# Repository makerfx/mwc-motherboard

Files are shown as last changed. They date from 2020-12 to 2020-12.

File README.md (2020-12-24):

# Magic Wheelchair Motherboard

The Magic Wheelchair Motherboard is a printed circuit board that makes it much easier to add interactivity to Magic Wheelchair builds (or other interactive projects).

Features include:
* Plug-in support for Teensy 4.1 and the Teensy 4 audio audio adaptor
* 4 channels of non-blocking addressable LEDs (ws2812, neopixel, etc.) full compatible with FastLED
* Stereo sound input, processing and output including volume control, filters, polyphonic sound output, multiple channels of simultaneous sd-card playback, FFT and peak level analysis and much more.
* Level-shifted GPIO
* Full breakout of all Teensy pins
* .91" OLED Screen for debugging or status
* Multiple channels of high-current transistor driven output
* Selectable voltage (5v or 12v) for addressable LED outputs
* Pluggable connectors for VIN, LED outputs and high-current outputs
* Small prototyping area for adding additional components
* Expansion header for connecting to a daughterboard
* Support for USB host mode through the Teensy 4.1 USB header

Note that this board is still in the development and testing phase. If you are interested in obtaining a board for a Magic Wheelchair project, or for another interactive project, [email us](mailto:info@makerfx.org) to learn the current status and availability of boards.
___
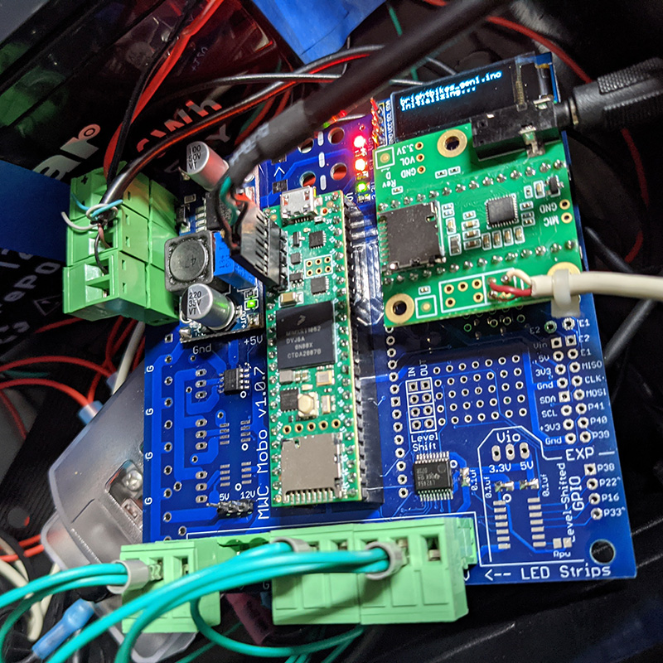
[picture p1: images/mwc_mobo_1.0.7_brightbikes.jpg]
MWC Motherboard prototype

MWC Motherboard prototype v1.0.7 being tested in a [BrightBikes](https://github.com/makerfx/brightbikes) LED art bike with more than 1600 audio-interactive addressable LEDs

BrightBikes holiday ride

BrightBikes fire demo

___
## History
In 2019, [we built the Bumblebee Transformer Magic Wheelchair for Alex](https://makezine.com/2019/02/08/watch-these-makers-transform-a-wheelchair-into-an-interactive-bumblebee-costume/) - that project was completed in just a few weeks, and we used the Teensy 3.6 with the Teensy 3 Audio Shield. We hand soldered protoboards for the circuits including the Teensy components, level shifters and high-current transistor outputs. Alex loved Bumblebee and Magic Wheelchair builders provided very positive feedback on the interactivity of the build. Just two weeks later, we were asked to help provide the electronics for another MWC build in Portland. Again, we created a hand-soldered protoboard. We realized that if we could make this part easier with a plug & play board for interactive MWC builds, we could help the build community significantly.

We've now worked through 7 revisions of the board, including upgrading to the Teensy 4.1 and the Teensy 4 Audio shield. We've added more functionality, and made it easier than every to get started. All our MWC build code is Open Source and available here to get builders up-to-speed quickly.

## Example Uses
* [Magic Wheelchair builds using this design]((http://www.makerfx.org/magic-wheelchair])) (includes prior generations of this circuit before the motherboard was created)
  * [Bumblebee Transformer code on GitHub](https://github.com/makerfx/mwc-bumblebee)
  * [Star Wars Tie Silencer code on GitHub](https://github.com/makerfx/mwc-tie-silencer)
  * [Guarians of the Galaxy Milano code on GitHub](https://github.com/makerfx/mwc-guardians-milano)
* BrightBikes - [Facebook](www.facebook.com/brightbikesorl) and [GitHub](https://github.com/makerfx/brightbikes)

## Bill of Materials
Note, not all parts are required. For example, if your build does not use high-current outputs, you don't need to populate those parts.

* PCB
  * If you want to purchase bare or populated boards, we are planning to make them available at some point in the future. Note that this board is still in the development and testing phase. If you are interested in obtaining a board for a Magic Wheelchair project, or for another interactive project, [email us](mailto:info@makerfx.org) to learn the current status and availability of boards.

* Teensy 4.1
  * QTY 1
  * Order from [PJRC](https://www.pjrc.com/store/teensy41.html) to support the creator.
  * We install header pins, so you can order with or without pins.

* Teensy Audio Adaptor Rev D
  * QTY 1
  * Order from [PJRC](https://www.pjrc.com/store/teensy3_audio.html) to support the creator.
  * REV D is for the Teensy 4 series, make sure you get the correct revision!
  * We install header pins, so you can order with or without pins.
  * This part is not required if the project does not have audio (but why not?!)

* LM2596 DC-DC Power Supply
  * QTY 1
  * [Amazon example](https://www.amazon.com/gp/product/B07VVXF7YX/)
  * Note that footprint is very important, there are several versions of similar boards
  * We typically run these systems off 12v batteries, this part does the regulation down to 5v, then the Teensy regulator provides 3.3v
  * SET THIS PART TO 5V BEFORE TYING ITS OUTPUTS TO THE PCB!

* .91" OLED Display (i2c)
  * QTY 1
  * [Amazon example](https://www.amazon.com/MELIFE-Display-SSD1306-3-3V-5V-Arduino/dp/B08F1ZBGLN/)
  * This part is optional and can be used for debugging or status displays. They are inexpensive and very helpful

* 2 pin Plug-in Screw terminal block 5.08mm pitch
  * QTY 8 (QTY 1 for VIN, QTY 5 for optional high-current out, QTY 2 for optional addl 5v and GND out)
  * [Amazon right angle example](https://www.amazon.com/gp/product/B07317PFSH/)
  * You can use straight or right angle as your packaging dictates

* 3 pin Plug-in Screw Terminal Block 5.08mm pitch
  * QTY 4 for LED outputs
  * [Amazon right angle example](https://www.amazon.com/gp/product/B07TC4WHZJ/)
  * You can use straight or right angle as your packaging dictates

* Male & Female header for mounting Teensy and Audio Adaptor and other items
  * QTY (Approx 80 pins female and 90 pins male for base use)
  * [Amazon set example](https://www.amazon.com/gp/product/B06Y4S6G29/)

* Settings jumpers [Amazon example](https://www.amazon.com/gp/product/B07Q3CDPXF)
  * QTY 2 (QTY 1 for LED voltage output, QTY 1 for level-shifted GPIO voltage)
  * We like red as a visual reminder to manage settings!

* LEDs
  * RED VIN LED SMD 0805
    * QTY 1
    * [Mouser example](https://www.mouser.com/ProductDetail/645-599-0110-007F/)
  * Orange 5V LED SMD 0805
    * QTY 1
    * [Mouser example](https://www.mouser.com/ProductDetail/645-599-0130-007F/)
  * Green 3.3V LED SMD 0805
    * QTY 1
    * [Mouser example](https://www.mouser.com/ProductDetail/645-599-0181-007F/)
  * LED Resistors
    * ADD PART HERE
    * QTY 3

* Addressable LED Output Buffer
  * SN74LV245ADBR Bus Transceiver [Datasheet](http://www.ti.com/general/docs/suppproductinfo.tsp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)
  * QTY 1
  * [Mouser](https://www.mouser.com/ProductDetail/595-SN74LV245ADBR/)
  * Technically this is optional, but if you aren't using the LEDs, this is likely not the right board for you!

* High-Current Output Drivers
  * TC4427ACOA713 Gate Driver 1.5A Dual [Datasheet](https://www.mouser.com/datasheet/2/268/21423F-63366.pdf)
  * QTY 3 (can be optionally populated based on number of high current outputs needed)
  * [Mouser](https://www.mouser.com/ProductDetail/579-TC4427ACOA713/)

* GPIO Level Shifter
  * TXS0104EDR BiDirectional Voltage Level Translator [datasheet](http://www.ti.com/general/docs/suppproductinfo.tsp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)
  * QTY 1 (optional)
  * [Mouser](https://www.mouser.com/ProductDetail/595-TXS0104EDR/)

* Misc Capacitors
  * .1uF SMD 0805
  * QTY 4? (Need to verify)
  * [Mouser Example](https://www.mouser.com/ProductDetail/581-08055C104K/)

* Battery Monitoring circuit (optional)
  * RvH
    * 4.7k SMD 0805 resistor
  * RvL
    * 1k SMD 0805 resistor
  * VRH
    * 1k SMD 0805 resistor
  * VCL
    * .1uF SMD 0805 capacitor
    * same as above in "Misc Capacitors
  * Vref
    * ZTL431BFFTA 2.5V reference - [Datasheet](https://www.mouser.com/datasheet/2/115/ZTL431-432-1499165.pdf)
    * QTY 1
    * [Mouser](https://www.mouser.com/ProductDetail/621-ZTL431BFFTA/)

* Other Handy Items
  * USB 5-pin header cable for Teensy 4.1 host mode
    * QTY 1
    * This is SUPER handy for adding a remote or other USB accessory
    * [Amazon example](https://www.amazon.com/Duttek-2-Pack-Motherboard-Adapter-Extender/dp/B06Y5RKMT8)
  * USB Remote
    * You can read all the buttons on this remote with the Teensy
    * It also supports a mouse mode
    * [Amazon](https://www.amazon.com/gp/product/B01FVUGPE8/)
  * 1/8" Headphone cable for audio input
    * I typically find a recycled cable, cut the end off and solder to the Teensy audio adapter input pads
  * 1/8" Headphone cable for audio output
    * I typically use a recycled headphone cable
  * Audio noise filter
    * Can be very helpful to reduce noise from LEDs in the circuit
    * (Amazon example)[https://www.amazon.com/dp/B0171PQLB8/]
  * Fuse block
    * If you have a LOT of LEDs, you may want to fuse the power circuits
    * We like the models that have bus terminals for both power AND ground
    * [Amazon example](https://www.amazon.com/gp/product/B08928WKGR)
  * 12v battery
    * We like this 12v LiFePo battery - we get about 2 hours of runtime from the 1600 LED art bikes, but these weigh 1/3 of the SLA equivalent!
    * Kaster 12.8V 12Ah LiFePO4 battery [eBay](https://www.ebay.com/itm/Kastar-12V-12AH-LifePO4-Battery-for-CATV-System-Robotics-E-Bike-Motorbike/254618882962)

## Disclaimer
This is a community-driven project and only affiliated with Magic Wheelchair as we are part of the builder community. The Magic Wheelchair organization is not responsible for any of this content, the design of the board, or any software.

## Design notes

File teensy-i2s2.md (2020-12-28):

# Teensy I2S Audio Input

For interactive audio projects, we've been using an external bluetooth receiver with an analog output to run into the Teensy Audio Adaptor analog input. While this works, the path is susceptible to noise, and it adds an extra module / cables.

Ideally, we'd like to take a Bluetooth audio module such as the CSR A64215 [Datasheet](https://www.tinyosshop.com/datasheet/CSRA64215%20QFN%20Data%20Sheet.pdf) and connect it directly to the Teensy via the second I2S input which uses the [i2s2 object in the Teensy Audio System Design Tool](https://www.pjrc.com/teensy/gui/?info=AudioInputI2S2).

## Teensy I2S Input Documentation

* Pins
  * Pin 3: LRCLK Output
    * This outputs the audio system frequency, typically 44.1kHz
  * Pin 4: BCLK Output
    * (This isnt working for me currently, so I don't have confirmed output)
  * Pin 5: RX Input
  * Pin 33: MCLK Output
    * This outputs 11.2 mHz
    * Not all devices need MCLK, the CSRA64215 does not appear to need MCLK

* Audio System Design Tool Object
  * There is an [i2s2 object in the Teensy Audio System Design Tool](https://www.pjrc.com/teensy/gui/?info=AudioInputI2S2) It has no configuration. Simply declaring it enables the output clocks.

* Master / Slave
  * The Teensy is best equipped to run as the master, and you send the clocks to the slave device, and then send the resulting audio data back to the Teensy.
  * The Teensy CAN run as a slave but then the [other audio in the system will not be clocked properly and *bad things happen*](https://forum.pjrc.com/threads/53824-Teensy-3-6-I2S-Slave-Mode-Question?p=188318&viewfull=1#post188318).

* Sample Rate
  * The Teensy operates at 44.1kHz by default. [It is possible to change this, and an easy change - however it can break a number of audio system functions](https://forum.pjrc.com/threads/60272-Time-for-a-new-Audiolibrary?p=236411&viewfull=1#post236411)
  * The CSRA64215 module runs at 48kHz by default, but has a configuration to change to other frequencies.

## CSRA64215 Documentation

* [CSRA64215 Datasheet](https://www.tinyosshop.com/datasheet)
* I purchased a common breakout on eBay
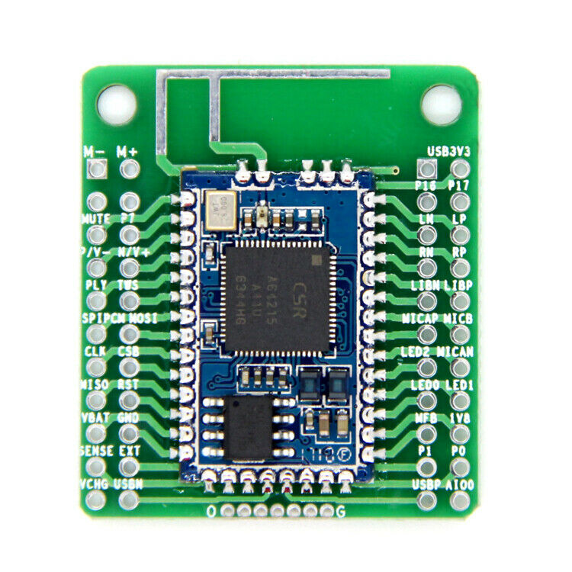
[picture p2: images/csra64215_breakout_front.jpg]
CSRA64215 Breakout PCB front

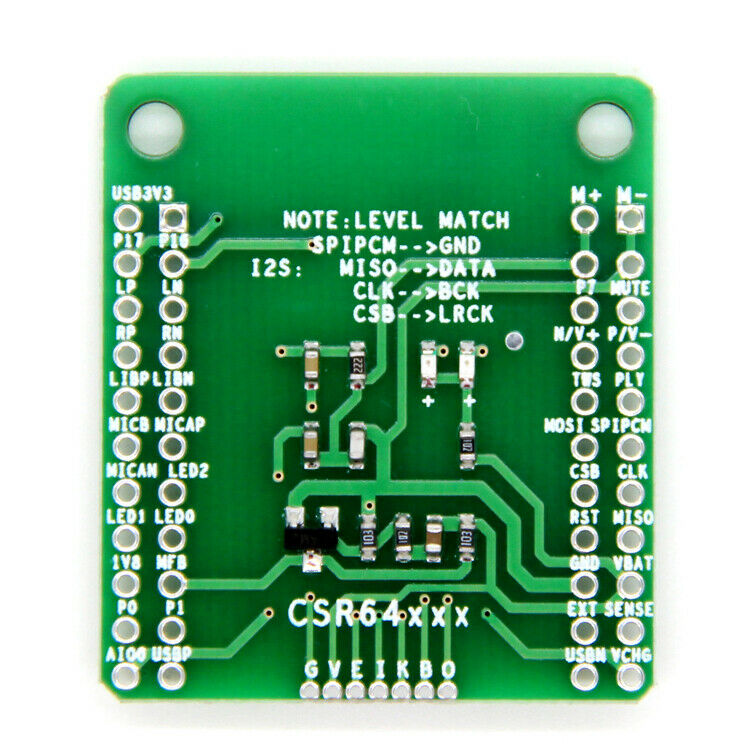
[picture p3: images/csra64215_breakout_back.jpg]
CSRA64215 Breakout PCB back


* [This guide](https://translate.google.com/translate?sl=auto&tl=en&u=https://suredsp.ratz-it.de/index.php?title%3DCSRA64215) (in German, but translates well) has great pictures of this module and connections for SPI programming and I2S

* I use the [CSR USB SPI programmer](https://www.tinyosshop.com/index.php?route=product/product&product_id=876) purchased from TinySine to update the module
SPI Connections
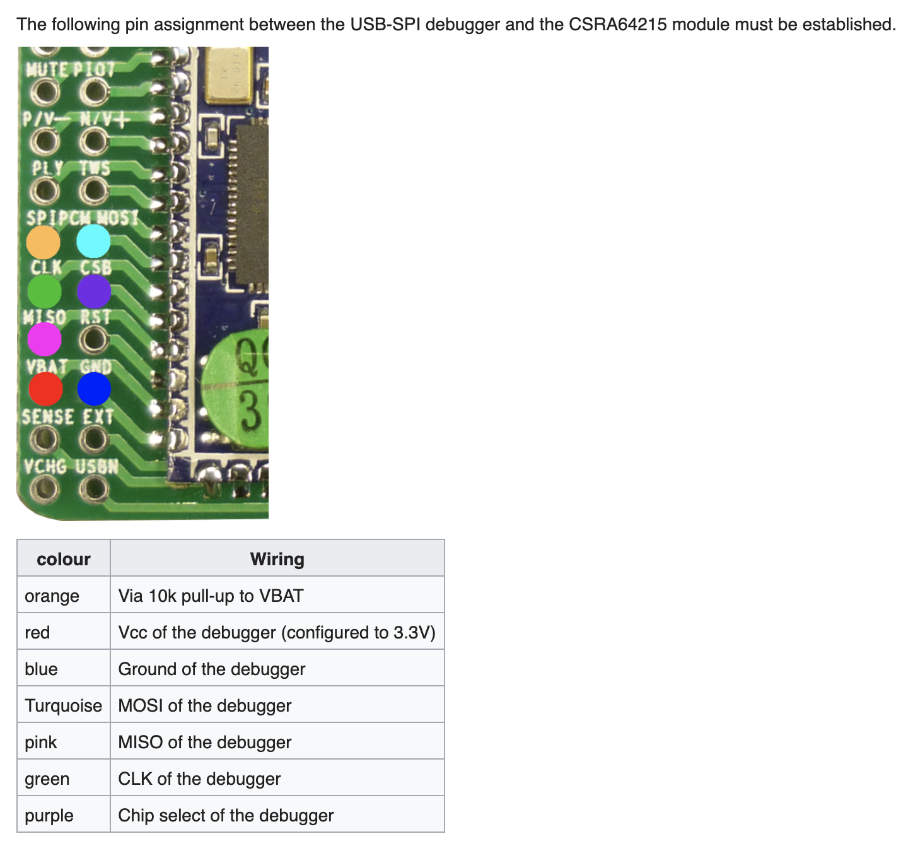
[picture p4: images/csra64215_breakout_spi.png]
CSRA64215 Breakout SPI

* Uploading Firmware
  * [Guide from TinySine](https://www.tinyosshop.com/how-to-restore-bluetooth-audio-module-default-settings)
* Changing Settings
  * Note that you need a settings profile that matches the firmware. For the modules purchased from eBay, I had to start by flashing the TinySine audioB firmware, then reading / writing settings
  * Changes
    * Bluetooth name
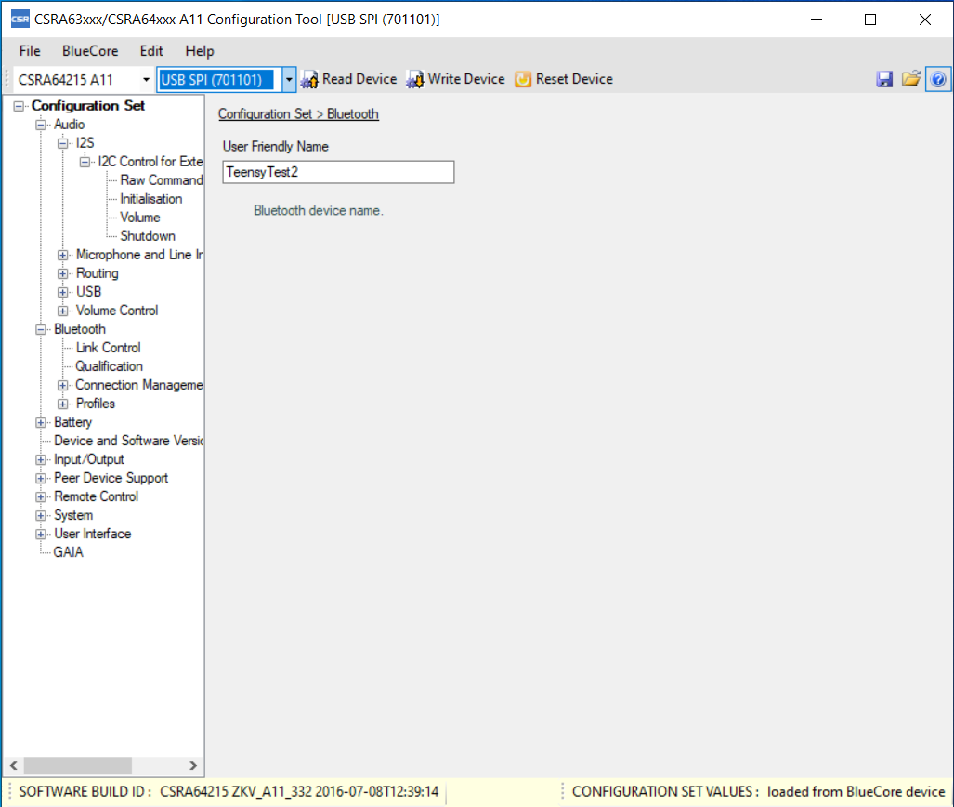
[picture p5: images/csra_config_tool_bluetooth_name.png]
CSRA Config tool screenshot
     
    * I2S Slave
    * 44.1kHz to match Teensy
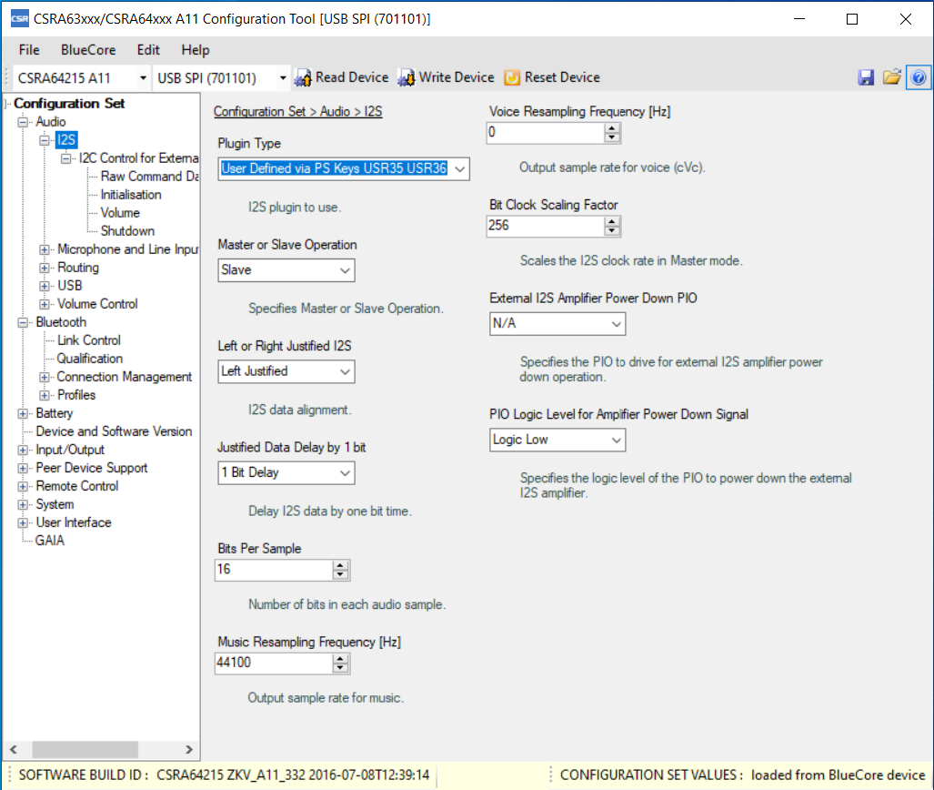
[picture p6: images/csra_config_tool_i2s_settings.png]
CSRA Config tool screenshot
    

  * There are a number of other cool settings including beeps and sounds (.wavs) when you have connected / disconnected, etc. but I've not experimented that far...

* Connecting to Teensy
  * THE CSRA64215 has 1.8V outputs, LEVEL SHIFTER IS REQUIRED!
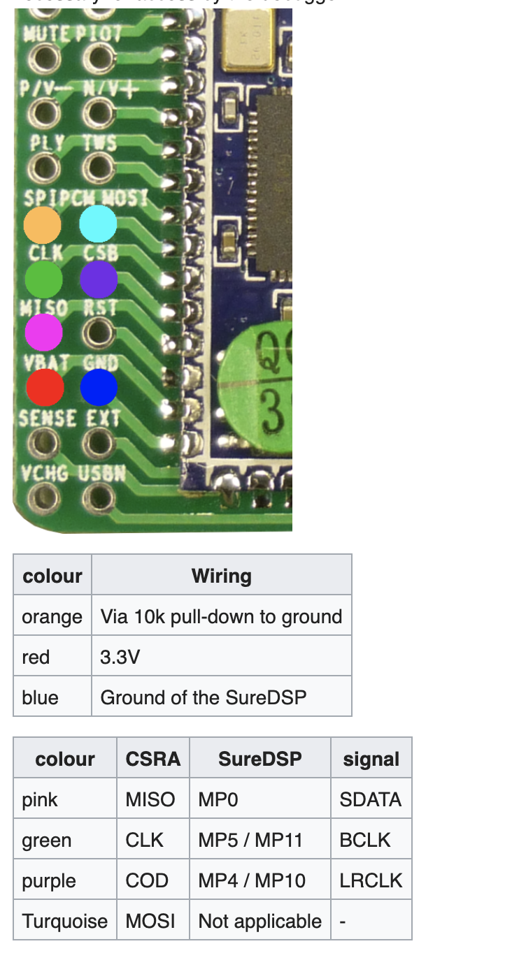
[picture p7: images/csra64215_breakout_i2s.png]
CSRA64215 Breakout I2S
  * I2S connections (from the guide linked above until we make specific Teensy diagrams)

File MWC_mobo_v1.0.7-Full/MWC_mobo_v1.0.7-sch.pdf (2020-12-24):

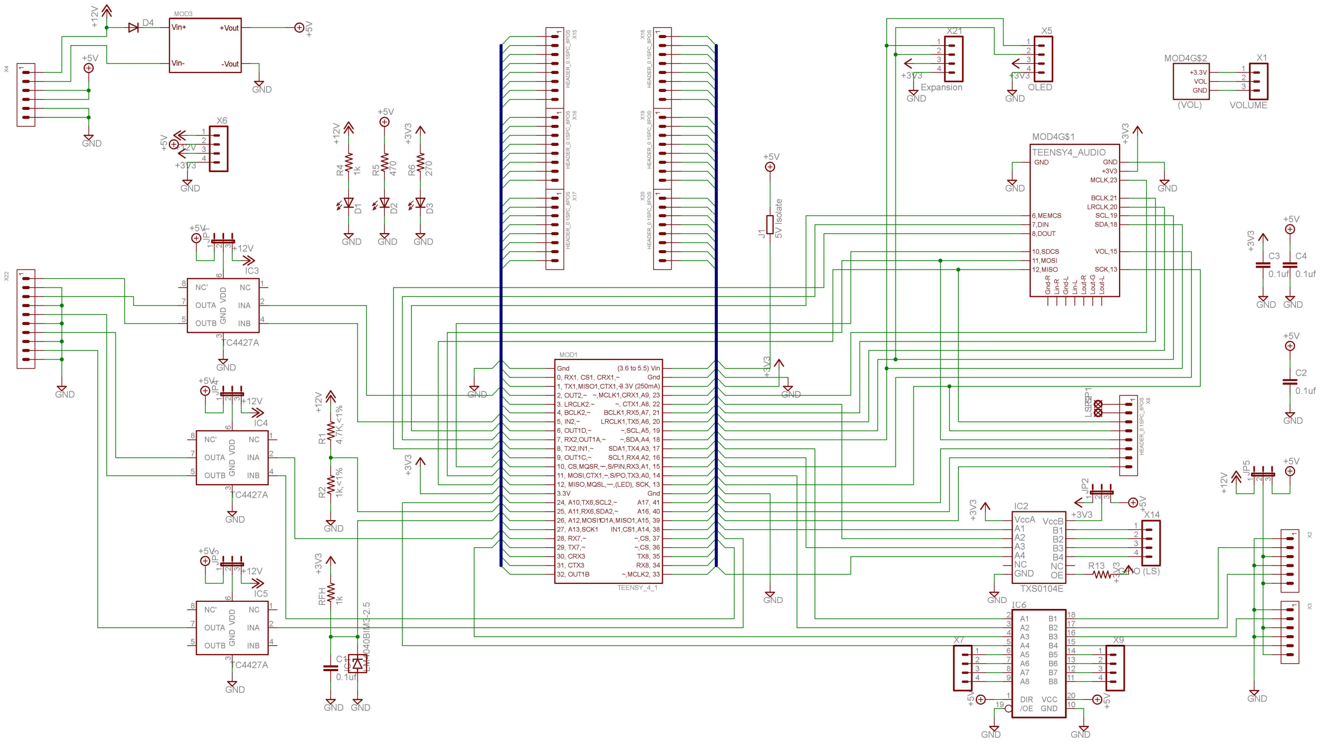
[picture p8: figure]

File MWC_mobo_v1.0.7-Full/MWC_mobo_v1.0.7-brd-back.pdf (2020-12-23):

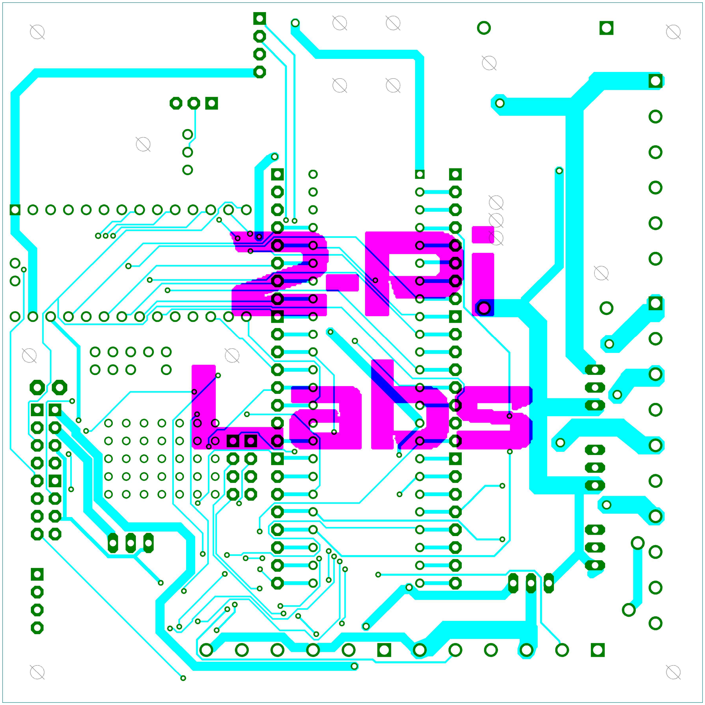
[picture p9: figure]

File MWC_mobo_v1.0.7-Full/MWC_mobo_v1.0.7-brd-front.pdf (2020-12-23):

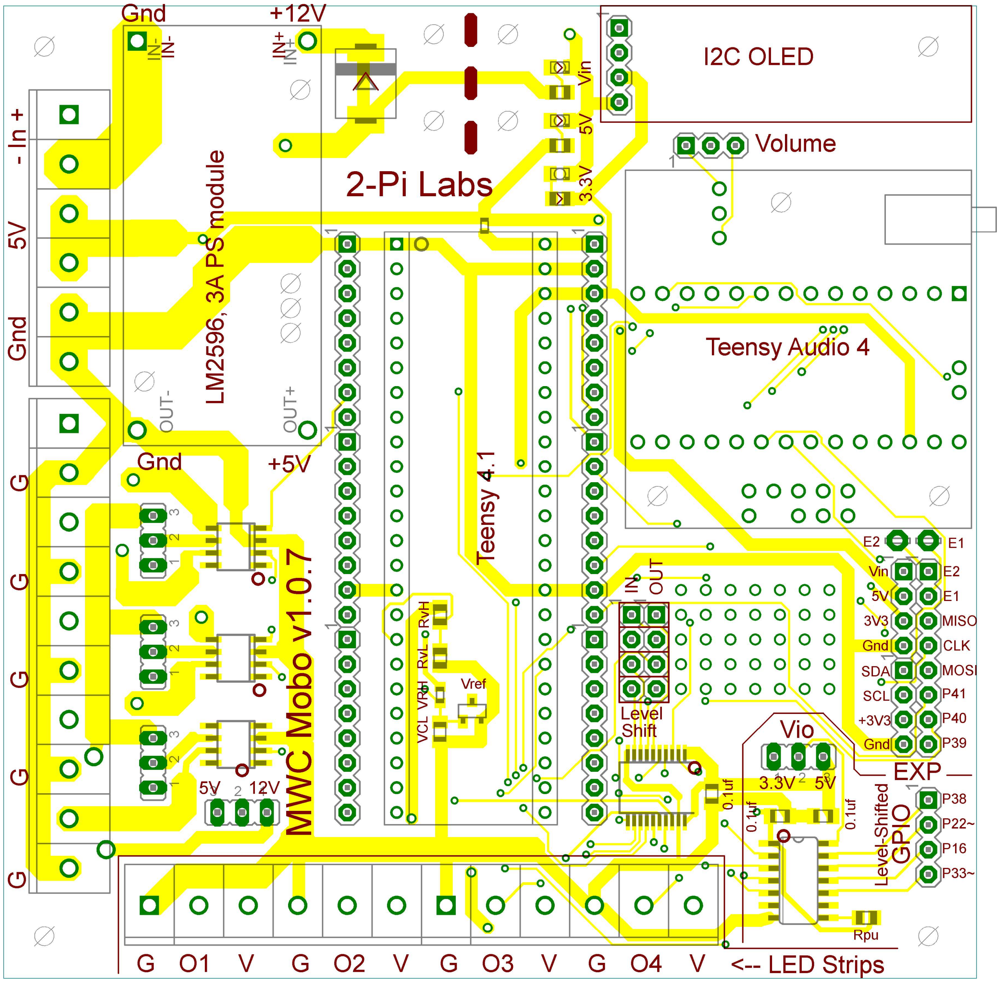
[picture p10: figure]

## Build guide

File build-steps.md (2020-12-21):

Bare PCB

Start with smallest components first

Power LEDs
VIN = Red
5V = Orange
3.3V = Green

LEDs are polarized
Small > in between pads indicates polarity; ground on the right
Some LEDs have arrow, others have Tee

Capacitor for level shifter

RvH= 4.7k
RvL= 1k

VRH = 1k
VCL = .1uf

Don't forget the bridge by the power LEDs

EROP-7SA-SE tweezers (mouser)

If ordering LEDs, get 0805 for ease of soldering

Voltage reference part - SOT-23-3 size, 2.5v reference - ZTL431BFFTA (Digikey) $0.40
Level Shifter TXS0104E

Tweezers - mouser AVEN 18072USA

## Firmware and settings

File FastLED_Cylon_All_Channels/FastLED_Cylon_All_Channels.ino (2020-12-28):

// FastLED Cylon Example, using Non-Blocking WS2812Serial

#include <WS2812Serial.h>
#define USE_WS2812SERIAL
#include <FastLED.h>

//oled screen includes
#include <Adafruit_GFX.h>
#include <Adafruit_SSD1306.h>
#define SCREEN_WIDTH 128 // OLED display width, in pixels
#define SCREEN_HEIGHT 32 // OLED display height, in pixels

// Declaration for an SSD1306 display connected to I2C (SDA, SCL pins)
#define OLED_RESET     4 // Reset pin # (or -1 if sharing Arduino reset pin)
Adafruit_SSD1306 display(SCREEN_WIDTH, SCREEN_HEIGHT, &Wire, OLED_RESET);

#define __FILENAME__ (strrchr(__FILE__, '/') ? strrchr(__FILE__, '/') + 1 : __FILE__)



// How many leds in your strip?
#define NUM_LEDS1 10
#define NUM_LEDS2 64
#define NUM_LEDS3 24
#define NUM_LEDS4 24

int numLEDs[4] = {10, 64, 24, 24};
int pinLEDs[4] = { 8, 26, 32, 33};

// Usable pins:
//   Teensy LC:   1, 4, 5, 24
//   Teensy 3.2:  1, 5, 8, 10, 31   (overclock to 120 MHz for pin 8)
//   Teensy 3.5:  1, 5, 8, 10, 26, 32, 33, 48
//   Teensy 3.6:  1, 5, 8, 10, 26, 32, 33
//   Teensy 4.0:  1, 8, 14, 17, 20, 24, 29, 39
#define DATA_PIN 32

// Define the array of leds
CRGB leds1[NUM_LEDS1];
CRGB leds2[NUM_LEDS2];
CRGB leds3[NUM_LEDS3];
CRGB leds4[NUM_LEDS4];

void setup() {
	Serial.begin(57600);
	Serial.println("resetting");
	LEDS.addLeds<WS2812SERIAL,14,RGB>(leds1,NUM_LEDS1);
  LEDS.addLeds<WS2812SERIAL,17,RGB>(leds2,NUM_LEDS2);
  LEDS.addLeds<WS2812SERIAL,24,RGB>(leds3,NUM_LEDS3);
  LEDS.addLeds<WS2812SERIAL,29,RGB>(leds4,NUM_LEDS4);
  
	LEDS.setBrightness(84);
  Serial.begin(115200);

    //display init
  // SSD1306_SWITCHCAPVCC = generate display voltage from 3.3V internally
  if(!display.begin(SSD1306_SWITCHCAPVCC, 0x3C)) { // Address 0x3C for 128x32
    Serial.println(F("SSD1306 allocation failed"));
    for(;;); // Don't proceed, loop forever
  }
  Serial.println("OLED begun");
  
  // Clear the buffer
  display.clearDisplay();

  // text display tests
  display.setTextSize(1);
  display.setTextColor(SSD1306_WHITE);
  display.setCursor(0,0);
  display.println(__FILENAME__);
  display.println(__DATE__);
  display.println(__TIME__);
  display.println("Initializing...");
  display.display(); // actually display all of the above
  delay(1000);
  
}

void fadeall() {
  for(int i = 0; i < 100; i++) {
    int imap1 = map(i,0, 100-1, 0, NUM_LEDS1-1);
    int imap2 = map(i,0, 100-1, 0, NUM_LEDS2-1);
    int imap3 = map(i,0, 100-1, 0, NUM_LEDS3-1);
    int imap4 = map(i,0, 100-1, 0, NUM_LEDS4-1);
    leds1[imap1].nscale8(250);
    leds2[imap2].nscale8(250);
    leds3[imap3].nscale8(250);
    leds4[imap4].nscale8(250); 
    } 
  }

void loop() {
	static uint8_t hue = 0;
	Serial.print("x");
	// First slide the led in one direction
	for(int i = 0; i < 100; i++) {
		// Set the i'th led to red
    int imap1 = map(i,0, 100-1, 0, NUM_LEDS1-1);
    int imap2 = map(i,0, 100-1, 0, NUM_LEDS2-1);
    int imap3 = map(i,0, 100-1, 0, NUM_LEDS3-1);
    int imap4 = map(i,0, 100-1, 0, NUM_LEDS4-1);

    
		leds1[imap1] = CHSV(hue++, 255, 255);
		leds2[imap2] = CHSV(hue++, 255, 255);
    leds3[imap3] = CHSV(hue++, 255, 255);
    leds4[imap4] = CHSV(hue++, 255, 255);
    // Show the leds
		FastLED.show();
		// now that we've shown the leds, reset the i'th led to black
		// leds[i] = CRGB::Black;
		fadeall();
		// Wait a little bit before we loop around and do it again
		delay(20);
	}
	Serial.print("x");

	// Now go in the other direction.
	for(int i = (100)-1; i >= 0; i--) {

    int imap1 = map(i,0, 100-1, 1, NUM_LEDS1-1);
    int imap2 = map(i,0, 100-1, 1, NUM_LEDS2-1);
    int imap3 = map(i,0, 100-1, 1, NUM_LEDS3-1);
    int imap4 = map(i,0, 100-1, 1, NUM_LEDS4-1);

		// Set the i'th led to red
		leds1[imap1] = CHSV(hue++, 255, 255);
		leds2[imap2] = CHSV(hue++, 255, 255);
    leds3[imap3] = CHSV(hue++, 255, 255);
    leds4[imap4] = CHSV(hue++, 255, 255);
    // Show the leds
		FastLED.show();
		// now that we've shown the leds, reset the i'th led to black
		// leds[i] = CRGB::Black;
		fadeall();
		// Wait a little bit before we loop around and do it again
		delay(20);
	}
}

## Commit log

2020-12-23 Add version 1.0.7
    Note this board has not been fully tested
    [MWC_mobo_v1.0.7.brd, MWC_mobo_v1.0.7.sch]
2020-12-24 Starting BOM
2020-12-24 added LEDs
2020-12-24 BOM updates
2020-12-24 Big updates to BOM including formatting
2020-12-24 building BOM
2020-12-24 add schematic PDF
2020-12-24 BOM improvements
2020-12-24 more bom updates
2020-12-24 update bom
2020-12-28 update pins for teensy 4.1 on v1.0.7 pcb
2020-12-28 add teensy i2s2 and CSRA64215 documentation
